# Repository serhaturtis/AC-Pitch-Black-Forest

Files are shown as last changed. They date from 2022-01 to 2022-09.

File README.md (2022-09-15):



<br />
<div align="center">
  <a href="https://github.com/serhaturtis/AC-Pitch-Black-Forest">
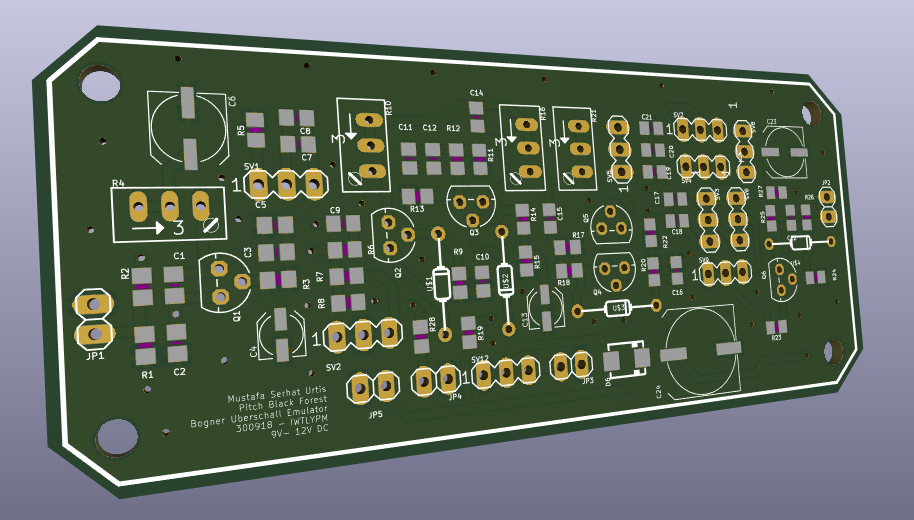
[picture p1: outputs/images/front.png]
    
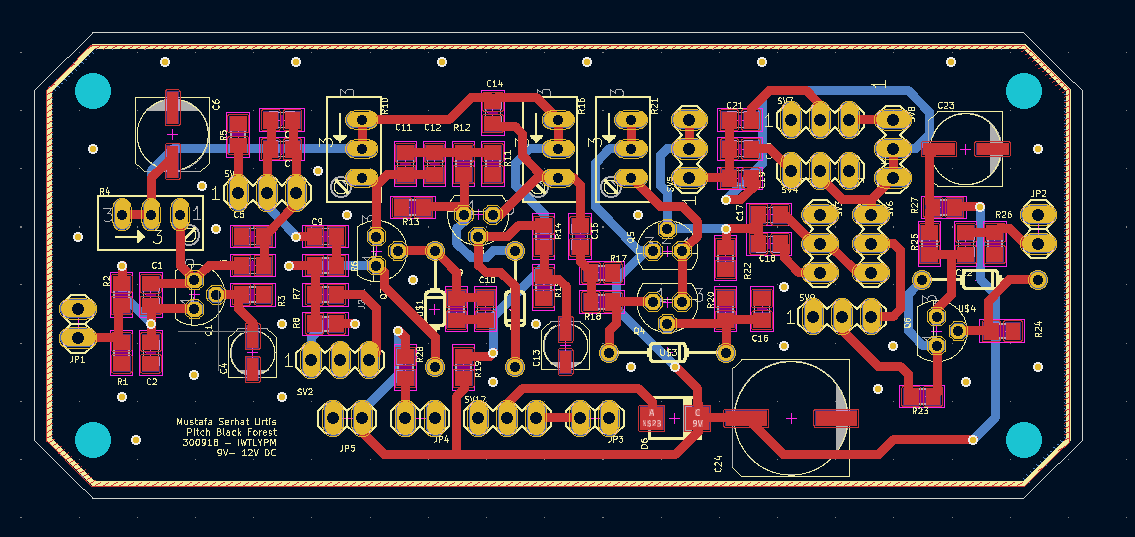
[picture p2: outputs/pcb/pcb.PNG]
    
  </a>

<h3 align="center">PITCH BLACK FOREST</h3>

  <p align="center">
    A Preamp Inspired By Ueberschall
  </p>
</div>

<!-- WHAT -->
## What?

This is a two stage guitar preamp board with gain, treble, mid, bass, voicing, filter bands and volume controls. And a boost switch.

## Why?

Because I wanted to experiment with JFETs and also have a small preamp board that I was going to use on another project.

## How?

This is imported from Eagle to KiCad 6 while I was backing up my projects. So the schematic's look is a bit janky.

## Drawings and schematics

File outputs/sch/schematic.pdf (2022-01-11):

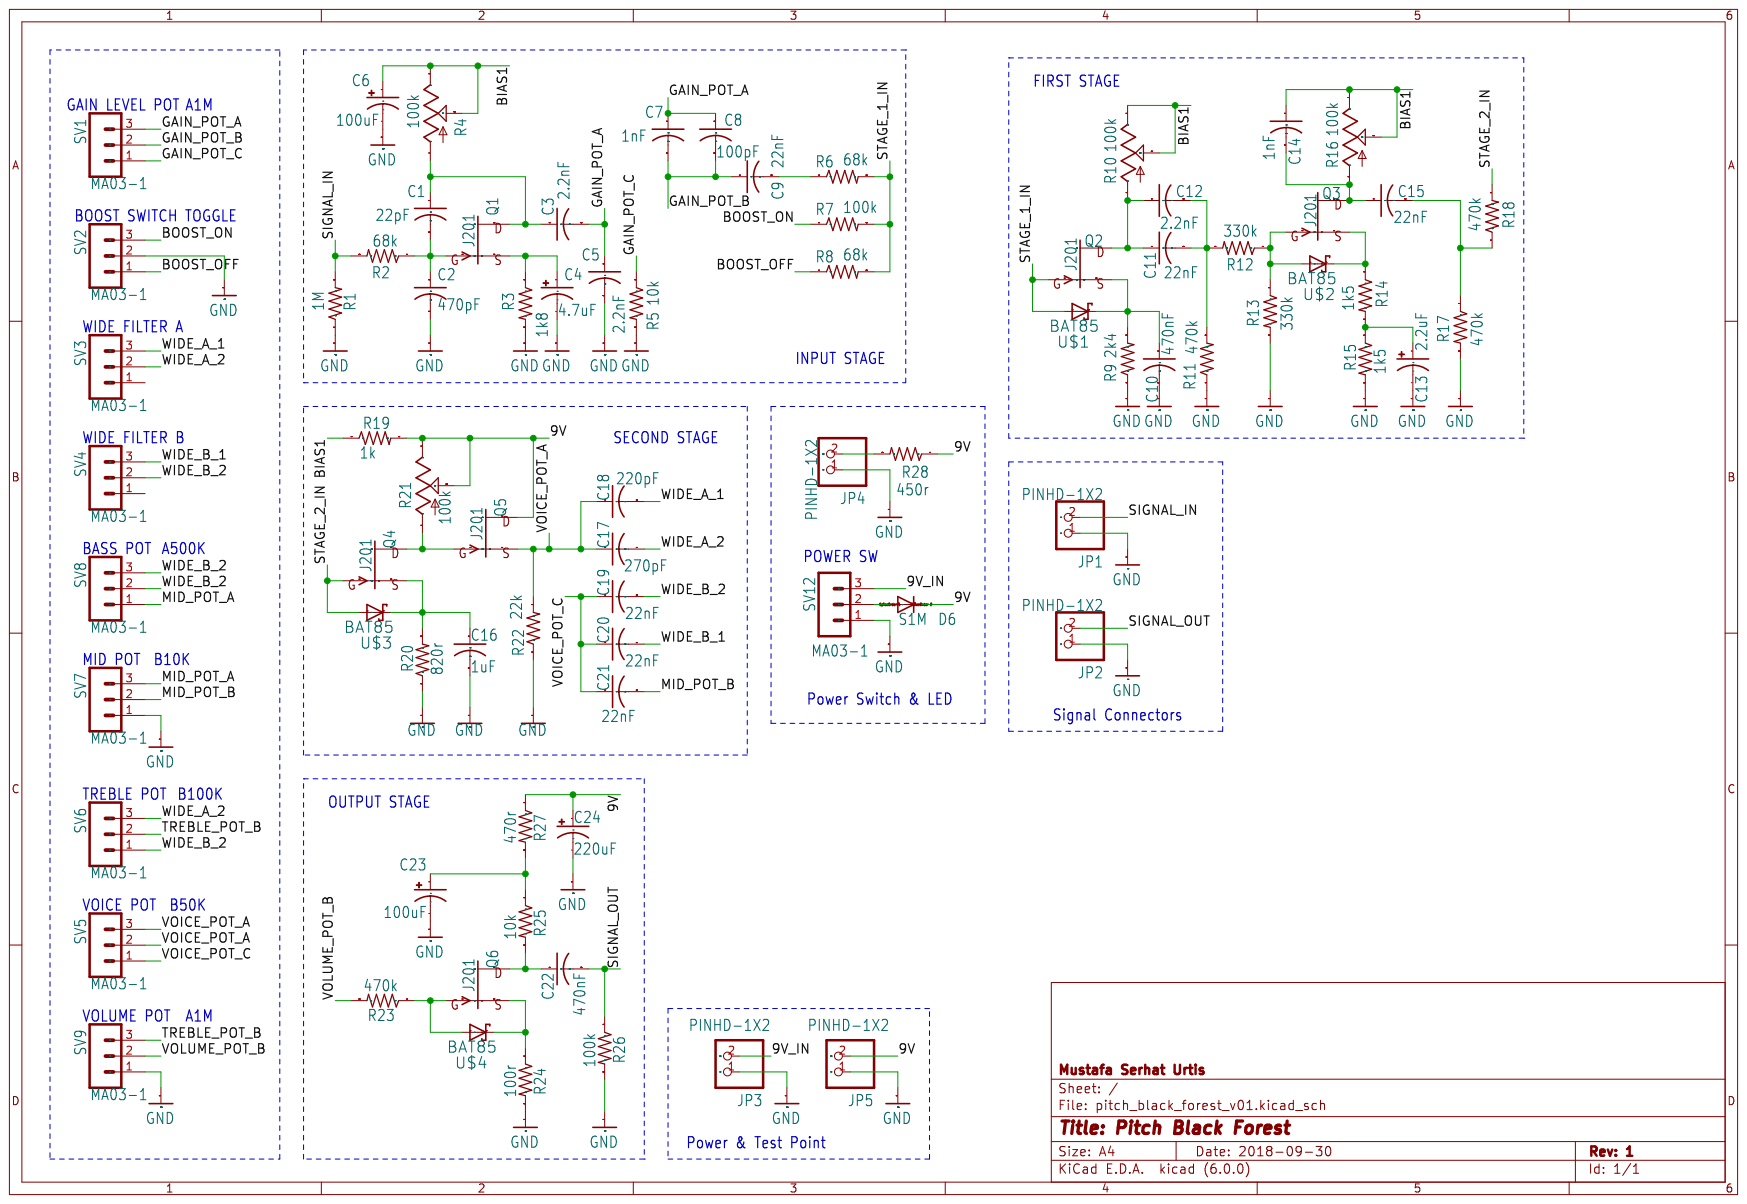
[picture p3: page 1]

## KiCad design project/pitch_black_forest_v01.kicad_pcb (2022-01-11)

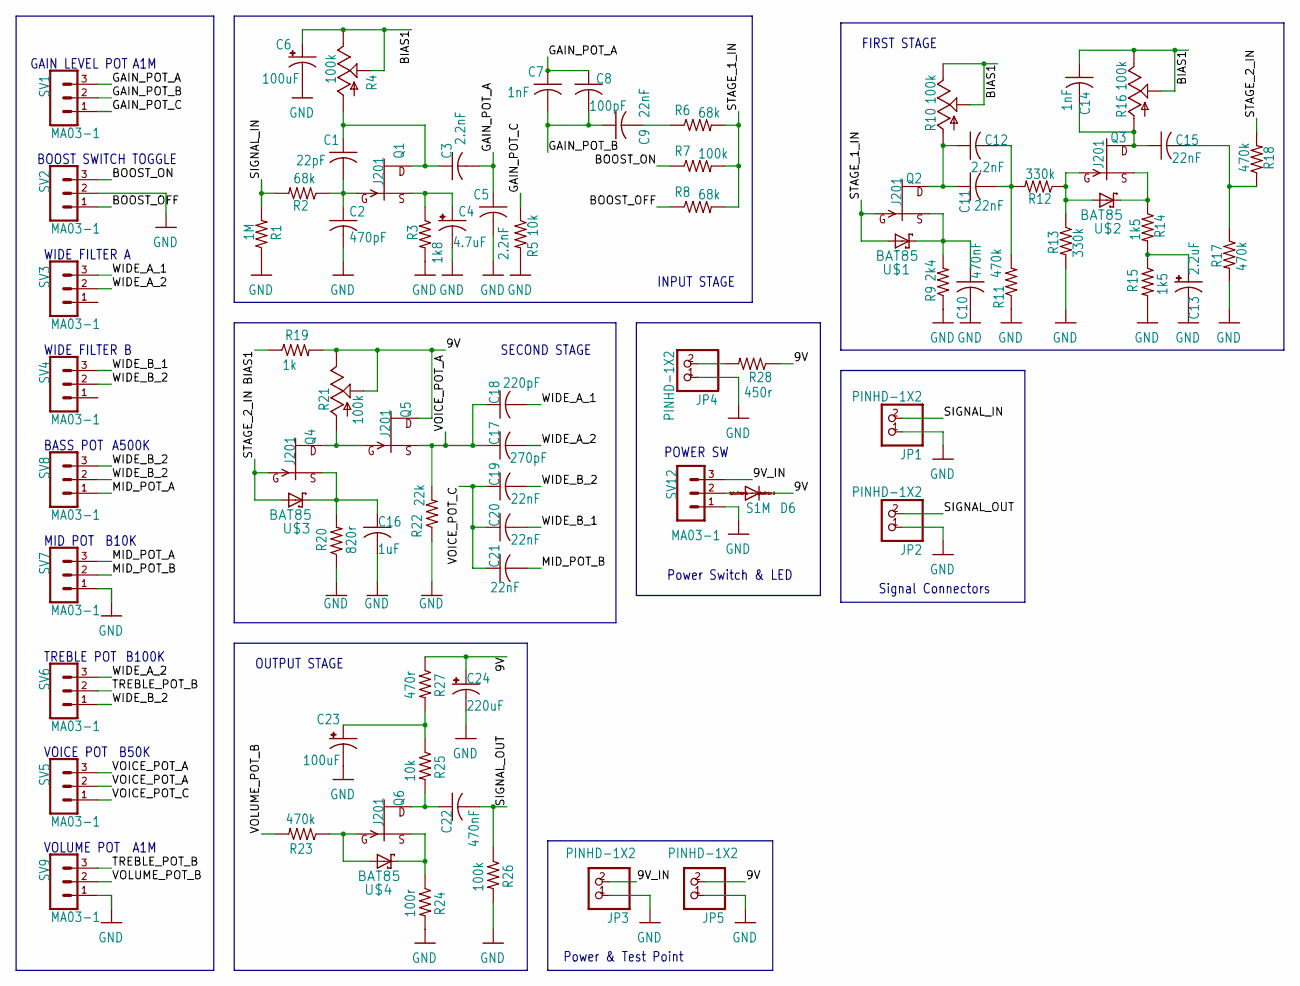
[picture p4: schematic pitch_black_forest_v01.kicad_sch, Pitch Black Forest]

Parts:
C1: 22pF; C0805
C2: 470pF; C0805
C3, C5, C12: 2.2nF; C0805
C4: 4.7uF; UD-4X5,8_NICHICON
C6, C23: 100uF; UD-6,3X5,8_NICHICON
C7, C14: 1nF; C0805
C8: 100pF; C0805
C9, C11, C15, C19, C20, C21: 22nF; C0805
C10, C22: 470nF; C0805
C13: 2.2uF; UD-4X5,8_NICHICON
C16: 1uF; C0805
C17: 270pF; C0805
C18: 220pF; C0805
C24: 220uF; UD-10X10_NICHICON
D6: S1M; SMA
JP1, JP2, JP3, JP4, JP5: PINHD-1X2; 1X02
Q1, Q2, Q3, Q4, Q5, Q6: J201; TO92
R1: 1M; R0805
R2, R6, R8: 68k; R0805
R3: 1k8; R0805
R4, R10, R16, R21: 100k; RJ9W
R5, R25: 10k; R0805
R7, R26: 100k; R0805
R9: 2k4; R0805
R11, R17, R18, R23: 470k; R0805
R12, R13: 330k; R0805
R14, R15: 1k5; R0805
R19: 1k; R0805
R20: 820r; R0805
R22: 22k; R0805
R24: 100r; R0805
R27: 470r; R0805
R28: 450r; R0805
SV1, SV2, SV3, SV4, SV5, SV6, SV7, SV8, SV9, SV12: MA03-1
U$1, U$2, U$3, U$4: BAT85; SOD68

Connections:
9V: C24.+, D6.C, JP5.2, Q5.3 (D), R19.2, R21.E, R21.S, R27.1, R28.1
9V_IN: JP3.2, SV12.3
BIAS1: C6.+, C14.1, R4.E, R4.S, R10.E, R10.S, R16.E, R16.S, R19.1
BOOST_OFF: R8.1, SV2.1
BOOST_ON: R7.1, SV2.3
GAIN_POT_A: C3.2, C5.1, C7.1, C8.1, SV1.3
GAIN_POT_B: C7.2, C8.2, C9.1, SV1.2
GAIN_POT_C: R5.1, SV1.1
GND: C2.2, C4.-, C5.2, C6.-, C10.2, C13.-, C16.2, C23.-, C24.-, JP1.1, JP2.1, JP3.1, JP4.1, JP5.1, R1.1, R3.2, R5.2, R9.1, R11.1, R13.2, R15.2, R17.2, R20.1, R22.1, R24.2, R26.2, SV2.2, SV7.1, SV9.1, SV12.1
MID_POT_A: SV7.3, SV8.1
MID_POT_B: C21.2, SV7.2
unnamed: C11.2, C12.2, R11.2, R12.2
unnamed: C1.2, C2.1, Q1.1 (G), R2.1
unnamed: C4.+, Q1.2 (S), R3.1
unnamed: C1.1, C3.1, Q1.3 (D), R4.A
unnamed: C9.2, R6.1
unnamed: Q3.1 (G), R12.1, R13.1, U$2.A
unnamed: C10.1, Q2.2 (S), R9.2, U$1.C (K)
unnamed: C11.1, C12.1, Q2.3 (D), R10.A
unnamed: Q3.2 (S), R14.1, U$2.C (K)
unnamed: C13.+, R14.2, R15.1
unnamed: C14.2, C15.1, Q3.3 (D), R16.A
unnamed: C15.2, R17.1, R18.1
unnamed: Q6.1 (G), R23.1, U$4.A
unnamed: C16.1, Q4.2 (S), R20.2, U$3.C (K)
unnamed: Q6.2 (S), R24.1, U$4.C (K)
unnamed: Q4.3 (D), Q5.1 (G), R21.A
unnamed: C22.1, Q6.3 (D), R25.2
unnamed: C23.+, R25.1, R27.2
unnamed: JP4.2, R28.2
unnamed: D6.A, SV12.2
SIGNAL_IN: JP1.2, R1.2, R2.2
SIGNAL_OUT: C22.2, JP2.2, R26.1
STAGE_1_IN: Q2.1 (G), R6.2, R7.2, R8.2, U$1.A
STAGE_2_IN: Q4.1 (G), R18.2, U$3.A
TREBLE_POT_B: SV6.2, SV9.3
VOICE_POT_A: C17.1, C18.1, Q5.2 (S), R22.2, SV5.2, SV5.3
VOICE_POT_C: C19.1, C20.1, C21.1, SV5.1
VOLUME_POT_B: R23.2, SV9.2
WIDE_A_1: C18.2, SV3.3
WIDE_A_2: C17.2, SV3.2, SV6.3
WIDE_B_1: C20.2, SV4.3
WIDE_B_2: C19.2, SV4.2, SV6.1, SV8.2, SV8.3

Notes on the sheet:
Signal Connectors
TREBLE POT
FIRST STAGE
B50K
BASS POT
WIDE FILTER A
VOLUME POT
A1M
VOICE POT
GAIN LEVEL POT
SECOND STAGE
B100K
A500K
MID POT
Power & Test Point
OUTPUT STAGE
Power Switch & LED
POWER SW
BOOST SWITCH TOGGLE
INPUT STAGE
WIDE FILTER B
B10K

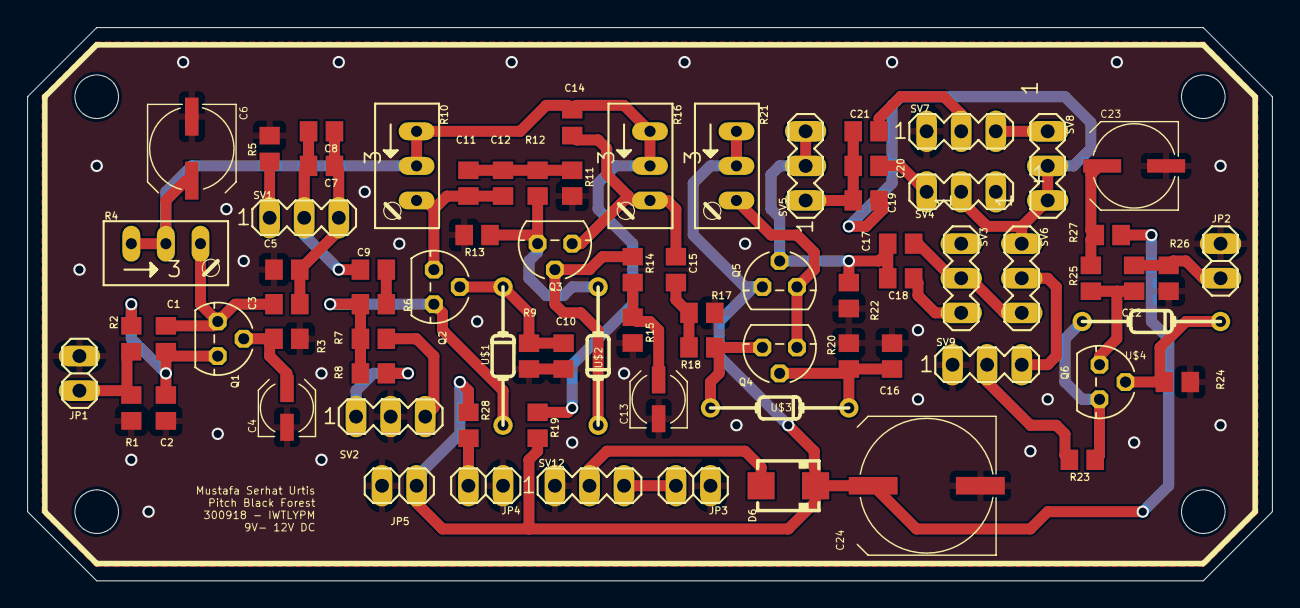
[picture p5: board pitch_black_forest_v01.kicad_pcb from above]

Board: 2 copper layers, 91.4 x 40.6 mm, 82 parts (0 on the bottom side), 43 nets.

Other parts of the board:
@HOLE0, @HOLE1, @HOLE2, @HOLE3: (no value)
